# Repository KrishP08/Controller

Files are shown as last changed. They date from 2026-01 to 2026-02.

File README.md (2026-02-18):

# Controller
This is xbox layout controller that have hall effect joystick,hall effect triggers,and two rumble motor,a,b,x,y,up,down,left,right,lb,rb,start,home,select and we use gp2040-ce firmware with pi pico W
# PCB 
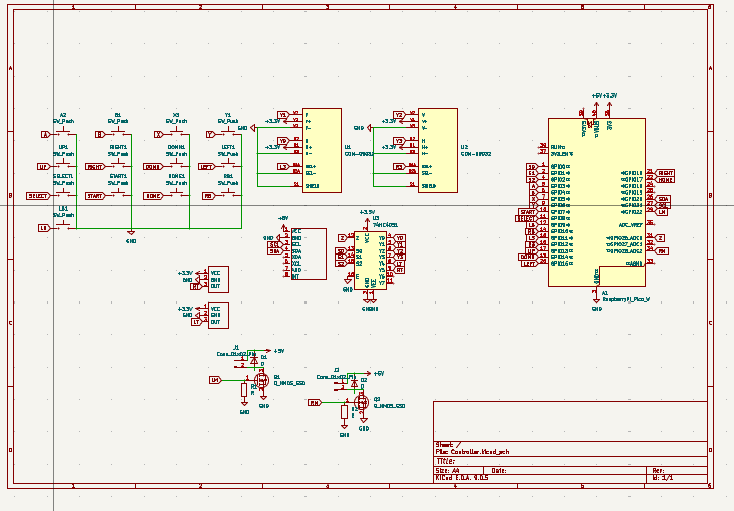
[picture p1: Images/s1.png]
Pcb Back

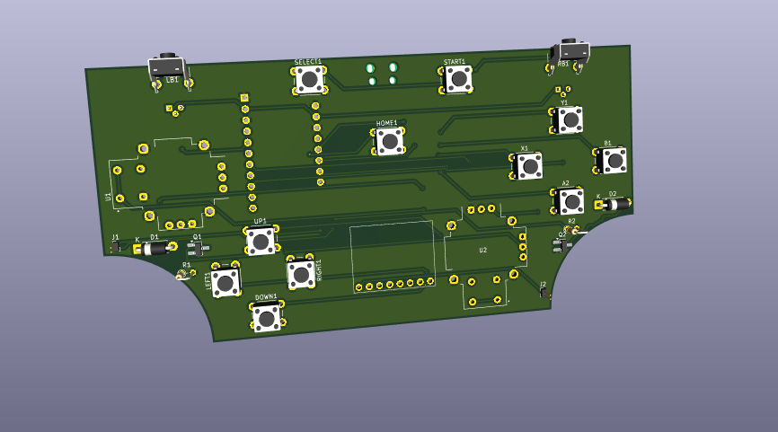
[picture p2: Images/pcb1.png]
Schematics

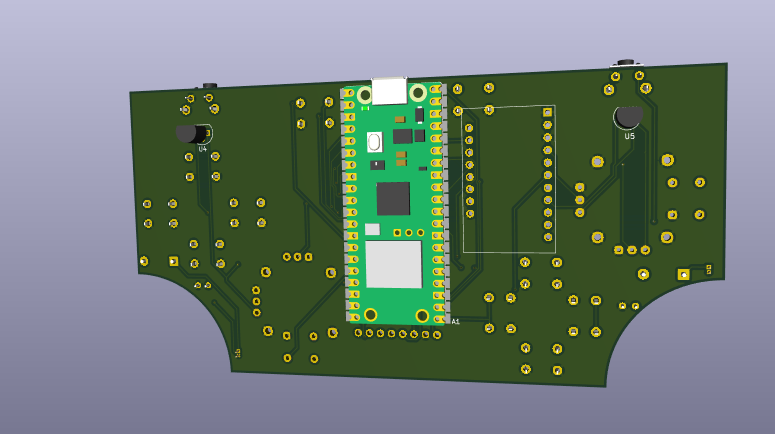
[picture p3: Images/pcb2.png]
Pcb Front


# CAD
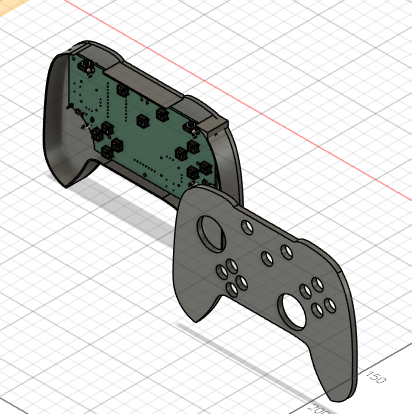
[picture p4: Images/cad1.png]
Case Front

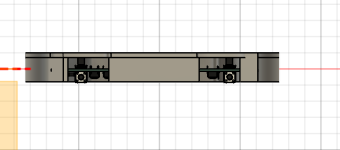
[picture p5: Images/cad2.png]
Case Back

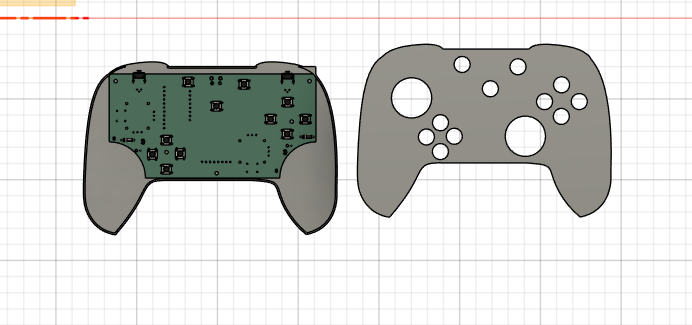
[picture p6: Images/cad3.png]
Case with pcb


# Firmware
In this we use gp2040-ce Firmware so for latest version go to https://gp2040-ce.info/ and select Pico w board firmware and download it 
# How to use 
First place and solder all the part
flast the firmware to pico 
then add pico to pcb 
To use web-based configuration aplication which can be started by holding HOME when plugging your controller into a PC or by holding HOME + LB + RB for five seconds while the controller is plugged in. Then access http://192.168.7.1 in a web browser to begin configuration.
Play

# why I made the project
I want to try make i my own controller that i can play on any consol without lossing any consols features 

# BOM

| No | Product Name | Qty | Price / Piece (₹) | Total (₹) | Total (USD) | Notes | Link |
| -: | --- | --: | ---: | ---: | ---: | --- | --- |
|  1 | Tactile Push Button Switch 6×6×5 |  14 | 2.00 | 28.00 | 0.02 | — | [Link](https://robu.in/product/6x6x5-tactile-push-button-switch/) |
|  2 | Raspberry Pi Pico W | 1 | 614.00 | 614.00 | 6.81 | — | [Link](https://robu.in/product/raspberry-pi-pico-w/) |
|  3 | 2PCS Hall Effect Sensor Joystick | 1 | 847.00 | 847.00 | 9.40 | — | [Link](https://www.amazon.in/dp/B0CNWYWCYN) |
|  4 | CJMCU-4051 (74HC4051) Analog Multiplexer | 1 | 76.00 | 76.00 | 0.84 | — | [Link](https://robu.in/product/cjmcu-4051-74hc4051-8-channel-analog-multiplexer/) |
|  5 | AO3400A MOSFET (30V, 5.2A) | 2 | 6.00 | 12.00 | 0.13 | — | [Link](https://robu.in/product/ao3400a-mosfet/) |
|  6 | 1N4148W Diode (75V, 150mA, SOD) | 2 | 1.43 | 2.86 | 0.03 | — | [Link](https://robu.in/product/1n4148w-slkor-75v-1v-4ns-150ma-sod-123-switching-diodes-rohs/) |
|  7 | 10kΩ 0.5W Metal Film Resistor | 2 | 0.98 | 1.96 | 0.02 | — | [Link](https://robu.in/product/10k-ohm-0-5w-metal-film-resistor-pack-of-50/) |
|  8 | Neodymium Magnet 4mm × 2mm (2 pcs) | 1 | 11.80 | 11.80 | 0.13 | — | [Link](https://roboticsdna.in/product/4mm-x-2mm-neodymium-disc-strong-magnet-2-piece/) |
|  9 | MPU-6050 3-Axis Accelerometer | 1 | 173.00 | 173.00 | 1.92 | — | [Link](https://robu.in/product/mpu-6050-gyro-sensor-2-accelerometer/) |
| 10 | Honeywell Hall Effect Sensor (SS49E) | 2 | 106.00 | 212.00 | 2.35 | — | [Link](https://robu.in/product/honeywell-board-mount-hall-effect-magnetic-sensors-ss49e/) |
| 11 | 4000 RPM 5V DC Vibration Motor | 2 | 29.00 | 137.00 | 1.52 | 58 + 79 Delivery | [Link](https://electronicspices.com/product/4000-rpm-5v-dc-vibration-rumble-motor) |
| 12 | PCB (JLCPCB) | 1 | 1934.74 | 1934.74 | 21.06 | 7.20 + 13.86 Delivery | [Link](https://jlcpcb.com/) |
| 13 | 3D Printed Enclosure | 1 | 1995.00 | 1995.00 | 22.13 | — | [Link](https://robu.in/product/3d-printing-service/) |
| 14 | KFC-A06W1-7.0-Tact Switch with Bracket  | 2 | 3 | 6 | 0.07 | — | [Link](https://robu.in/product/kfc-a06w1-7-0-tact-switch-with-bracket-2-pin6x6x7/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) |
| | **Total** | | | **₹ 6051.36** | **$ 66.72** | | |

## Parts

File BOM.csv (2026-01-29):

No | Product Name | Quantity | Price per Piece (₹) | Total Price (₹) | Total Price in USB | Note | Link
1 | Tactile Push Button Switch 6x6x5 | 2 | 14 | 28 | 0.30 |  | https://robu.in/product/6x6x5-tactile-push-button-switch/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
2 | Raspberry PI PICO W | 1 | 614 | 614 | 6.81 |  | https://robu.in/product/raspberry-pi-pico-w/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
3 | 2PCS Hall Effect Sensor Joystick | 1 | 847 | 847 | 9.40 |  | https://www.amazon.in/Effect-Analog-Joystick-Replacement-Potentiometer/dp/B0CNWYWCYN
4 | CJMCU-4051 74HC4051 8 Channel Analog Multiplexer/ | 1 | 76 | 76 | 0.84 |  | https://robu.in/product/cjmcu-4051-74hc4051-8-channel-analog-multiplexerdemultiplexer-sensor-module-breakout-board-arduino/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
5 | AO3400A-HUASHUO-30V 5.2A | 2 | 6 | 12 | 0.13 |  | https://robu.in/product/cjmcu-4051-74hc4051-8-channel-analog-multiplexerdemultiplexer-sensor-module-breakout-board-arduino/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
6 | 1N4148W-Slkor-75V 1V 4ns 150mA SOD | 2 | 1.43 | 2.86 | 0.03 |  | https://robu.in/product/1n4148w-slkor-75v-1v-4ns-150ma-sod-123-switching-diodes-rohs/?gad_source=1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
7 | 10k Ohm 0.5W Metal Film Resistor | 2 | 0.98 | 1.96 | 0.02 |  | https://robu.in/product/10k-ohm-0-5w-metal-film-resistor-pack-of-50/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
8 | 4mm x 2mm Neodymium Disc Strong Magnet (2 Piece) | 1 | 11.8 | 11.8 | 0.13 |  | https://roboticsdna.in/product/4mm-x-2mm-neodymium-disc-strong-magnet-2-piece/?src=google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
9 | MPU-6050 3-Axis Accelerometer | 1 | 173 | 173 | 1.92 |  | https://robu.in/product/mpu-6050-gyro-sensor-2-accelerometer/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
10 | HONEYWELL Board Mount Hall Effect/Magnetic Sensor-SS49E, | 2 | 106 | 212 | 2.35 |  | https://robu.in/product/honeywell-board-mount-hall-effect-magnetic-sensors-ss49e-flat-to-92-3-0vdc-ratiometric-pcb/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
11 | 4000 RPM 5V DC Vibration Rumble Motor | 2 | 29 | 137 | 1.52 | 58 + 79(Deliver)) | https://electronicspices.com/product/4000-rpm-5v-dc-vibration-rumble-motor
12 | PCB | 1 | 1934.74 | 1934.74 | 21.06 | 7.20+13.86(Deliver) | https://jlcpcb.com/
13 | 3D print | 1 | 1,995 | 1995 | 22.13 |  | https://robu.in/product/3d-printing-service/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
14 | KFC-A06W1-7.0-Tact Switch with Bracket | 2 | 3 | 6 | 0.07
 |  | Total |  | 6051.36 | 66.72

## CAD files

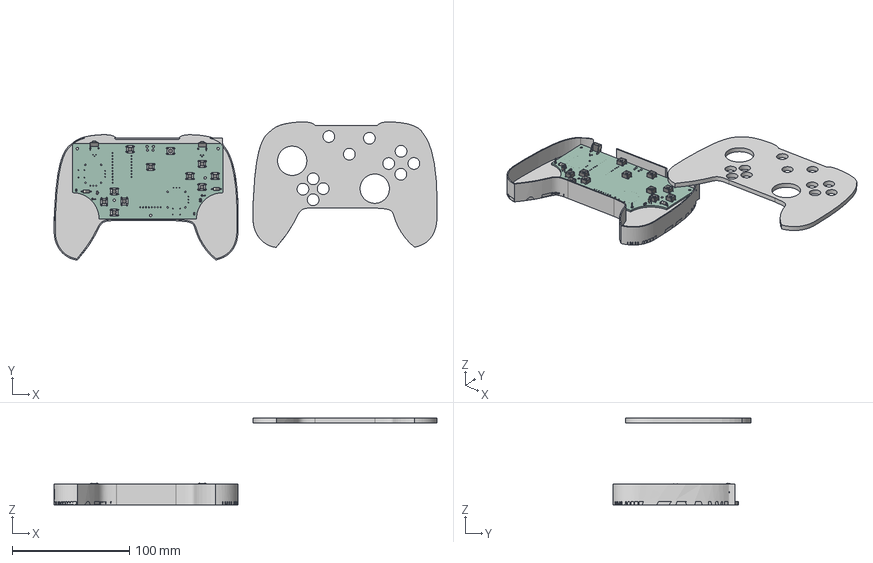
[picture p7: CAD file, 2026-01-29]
CAD/CONTROLLER 3D.step
326.7 x 117.9 x 74.0 mm
SW_PUSH_6mm x 11
D_DO-41_SOD81_P7.62mm_Horizontal x 2
R_Axial_DIN0204_L3.6mm_D1.6mm_P2.54mm_Vertical x 2
SW_Tactile_SPST_Angled_PTS645Vx39-2LFS x 2
SOT-23 x 2
PinHeader_1x02_P1.00mm_Vertical x 2
TO-92 x 2
RaspberryPi_Pico_W_Module_KiCad
Controller_PCB

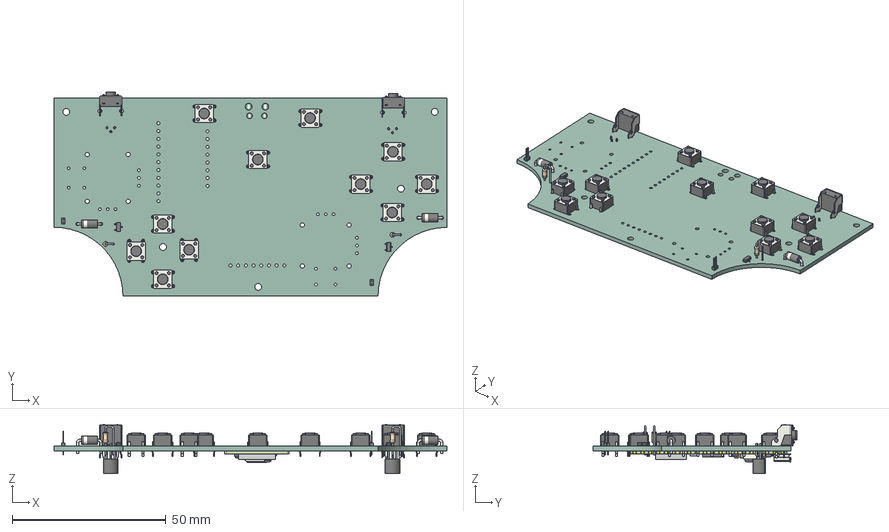
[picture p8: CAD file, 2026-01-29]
PCB/Controller.step
128.0 x 66.5 x 16.0 mm
SW_PUSH_6mm x 11
D_DO-41_SOD81_P7.62mm_Horizontal x 2
R_Axial_DIN0204_L3.6mm_D1.6mm_P2.54mm_Vertical x 2
SW_Tactile_SPST_Angled_PTS645Vx39-2LFS x 2
SOT-23 x 2
PinHeader_1x02_P1.00mm_Vertical x 2
TO-92 x 2
RaspberryPi_Pico_W_Module_KiCad
Controller_PCB

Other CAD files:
CAD/CONTROLLER+3D.f3z

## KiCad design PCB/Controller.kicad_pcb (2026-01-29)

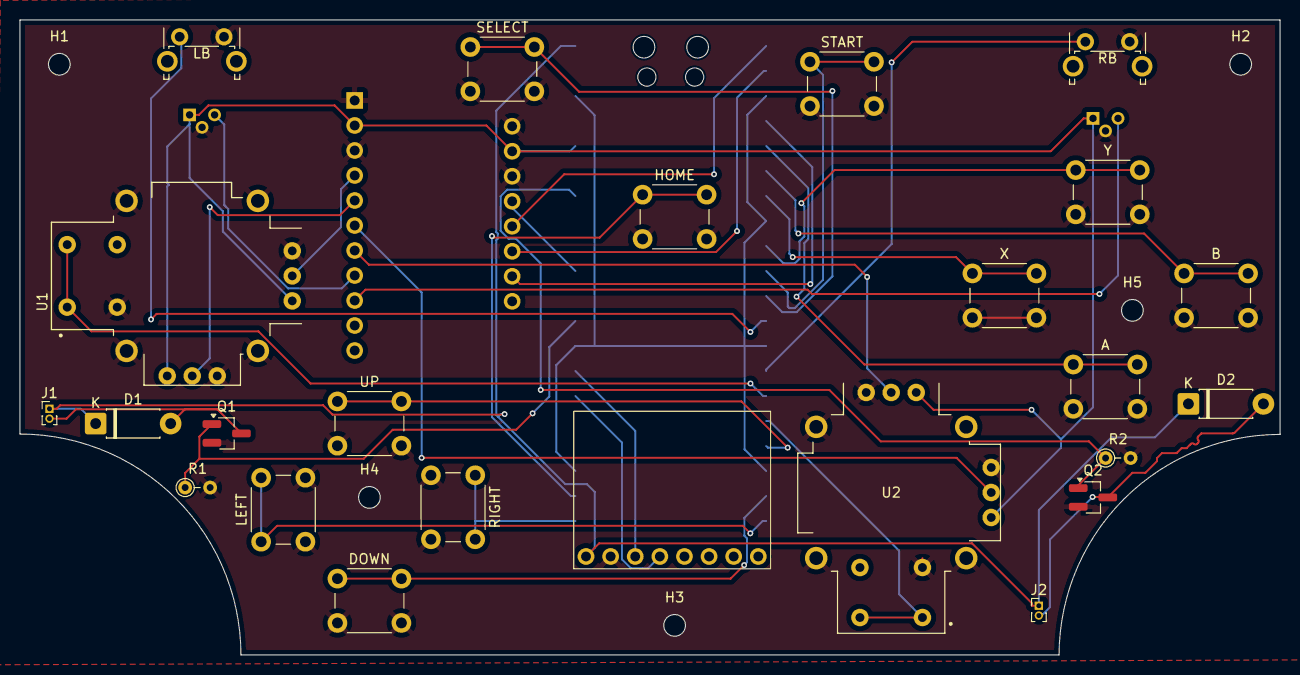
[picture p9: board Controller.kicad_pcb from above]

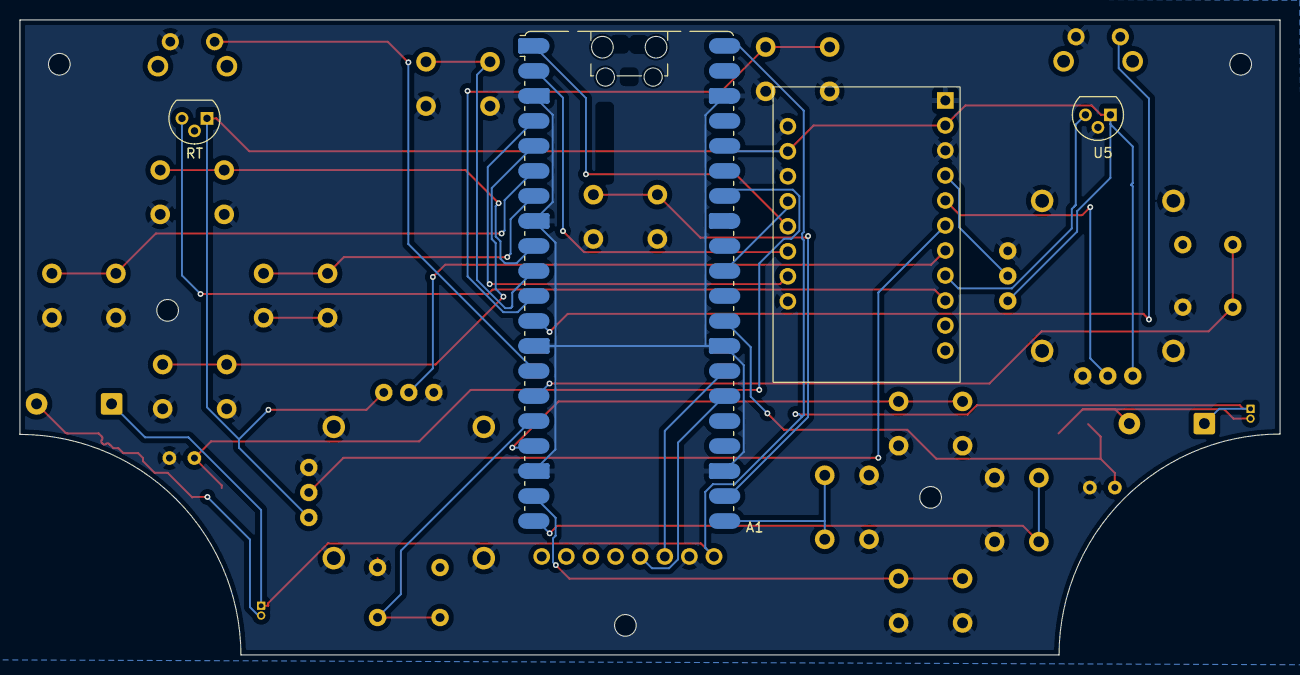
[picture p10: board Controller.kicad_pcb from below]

Board: 2 copper layers, 128.0 x 64.5 mm, 33 parts (4 on the bottom side), 34 nets.

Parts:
A: SW_Push; SW_PUSH_6mm
A1: RaspberryPi_Pico_W; RaspberryPi_Pico_W_SMD_HandSolder
B: SW_Push; SW_PUSH_6mm
D1, D2: D; D_DO-41_SOD81_P7.62mm_Horizontal
DOWN: SW_Push; SW_PUSH_6mm
H1: MH_2.2mm; MountingHole_2.2mm_M2_DIN965
H2, H3, H4, H5: MountingHole_2.2mm_M2_DIN965
HOME: SW_Push; SW_PUSH_6mm
J1, J2: Conn_01x02_Pin; PinHeader_1x02_P1.00mm_Vertical
LB: SW_Push; SW_Tactile_SPST_Angled_PTS645Vx39-2LFS
LEFT: SW_Push; SW_PUSH_6mm
MPU1: MPU6050; mpu6050
Q1, Q2: Q_NMOS_GSD; SOT-23_Handsoldering
R1, R2: R; R_Axial_DIN0204_L3.6mm_D1.6mm_P2.54mm_Vertical
RB: SW_Push; SW_Tactile_SPST_Angled_PTS645Vx39-2LFS
RIGHT: SW_Push; SW_PUSH_6mm
RT: TO-92
SELECT: SW_Push; SW_PUSH_6mm
START: SW_Push; SW_PUSH_6mm
U1, U2: COM-09032; XDCR_COM-09032
U3: 74HC4051
U5: TO-92
UP: SW_Push; SW_PUSH_6mm
X: SW_Push; SW_PUSH_6mm
Y: SW_Push; SW_PUSH_6mm

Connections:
+3.3V: A1.36 (3V3), RT.1 (VCC), U1.H1 (H+), U1.V1 (V+), U2.H1 (H+), U2.V1 (V+), U3.2 (VCC), U5.1 (VCC)
+5V: A1.40 (VBUS), D1.1 (K), D2.1 (K), J1.1, J2.1, MPU1.1 (VCC)
A: A.1, A1.5 (GPIO3)
B: A1.6 (GPIO4), B.1
DOWN: A1.19 (GPIO14), DOWN.1
GND: A.2, A1.3 (GND), A1.8 (GND), A1.13 (GND), A1.18 (GND), A1.23 (GND), A1.28 (GND), A1.38 (GND), B.2, DOWN.2, HOME.2, LB.2, LEFT.2, MPU1.2 (GND), Q1.2 (S), Q2.2 (S), R1.2, R2.2, RB.2, RIGHT.2, RT.2 (GND), SELECT.2, START.2, U1.B2A (SEL-), U1.H3 (H-), U1.S1 (SHIELD), U1.S2 (SHIELD), U1.S3 (SHIELD), U1.S4 (SHIELD), U1.V3 (V-), U2.B2A (SEL-), U2.H3 (H-), U2.S1 (SHIELD), U2.S2 (SHIELD), U2.S3 (SHIELD), U2.S4 (SHIELD), U2.V3 (V-), U3.1 (VEE), U3.3 (GND), U3.16 (E), U5.2 (GND), UP.2, X.2, Y.2
HOME: A1.22 (GPIO17), HOME.1
L3: A1.15 (GPIO11), U1.B1A (SEL+), U1.B1B
LB: A1.12 (GPIO9), LB.1
LEFT: A1.20 (GPIO15), LEFT.1
LM: A1.29 (GPIO22), Q1.1 (G), R1.1
LT: U3.8 (Y4), U5.3 (OUT)
unnamed: D1.2 (A), J1.2, Q1.3 (D)
unnamed: D2.2 (A), J2.2, Q2.3 (D)
R3: A1.16 (GPIO12), U2.B1A (SEL+), U2.B1B
RB: A1.14 (GPIO10), RB.1
RIGHT: A1.21 (GPIO16), RIGHT.1
RM: A1.34 (GPIO28_ADC2), Q2.1 (G), R2.1
RT: RT.3 (OUT), U3.9 (Y5)
S0: A1.1 (GPIO0), U3.13 (S0)
S1: A1.2 (GPIO1), U3.14 (S1)
S2: A1.4 (GPIO2), U3.15 (S2)
SCL: A1.27 (GPIO21), MPU1.3 (SCL)
SDA: A1.26 (GPIO20), MPU1.4 (SDA)
SELECT: A1.11 (GPIO8), SELECT.1
START: A1.10 (GPIO7), START.1
UP: A1.17 (GPIO13), UP.1
X: A1.7 (GPIO5), X.1
Y: A1.9 (GPIO6), Y.1
Y0: U1.H2 (H), U3.4 (Y0)
Y1: U1.V2 (V), U3.5 (Y1)
Y2: U2.V2 (V), U3.6 (Y2)
Y3: U2.H2 (H), U3.7 (Y3)
Z: A1.31 (GPIO26_ADC0), U3.12 (Z)
